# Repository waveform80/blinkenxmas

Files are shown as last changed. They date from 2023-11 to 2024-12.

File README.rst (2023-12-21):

=============
Blinken' Xmas
=============

Are you sitting comfortably? Then I'll begin …

A long time ago, in a land far, far away called "Manchester", there lived the
Jones family. At this festive time of year they would put up their ceremonial
totem, the "Asda 6ft Pre-Lit Green Christmas Tree". But 'twas the year of the
Great Plague, and even the electrickery faired poorly, and lo! The Asda 6ft
Pre-Lit Green Christmas Tree had become The Asda 6ft Not-Even-Slightly-Lit
Green Christmas Tree, not Pre-Lit, nor Lit, but possibly Post-Lit.

And all were most vexed.

In the great drawer of unstatic bags in the loft, there lived the `neopixies`_.
And they cried out, "use us, for we shall bring light and all manner of
blinkeness to your tree!" So the one called "Dave" gathered together 150 of the
neopixies, and waved his magic Pico at them [#wrong1]_, and the tree glowed
brightly with their warmth.

And it was Good.

But the neopixies were not content with glowing warm white all the time, and
whispered to Dave that they could make all the colours of the rainbow, if only
he would wave his magic Pico a bit more [#wrong2]_. And so Dave set to work,
and after much toil (and no small amount of "why is the tree dark? Can't you
just make it one colour, again? That was fine!"), the tree was lit once more,
but this time with all the colours of the rainbow! But the design was rough;
mere anarchy loosed upon the innocent eyeballs of the viewer [#sorry1]_. And
all who saw it did whisper, "it's very colourful, but in a unicorn vomit sort
of a way".

And lo! A `message from the Prophet Parker`_ did appear.

And it was good. If a bit thin on detail. I mean, where's the calibration trig?
But Dave was unperturbed and vowed that he would wrangle the neopixies with his
mathemagic and bring order to the Asda 6ft Unicorn-Vomit Christmas Tree. But
his `trigo-gnometry`_ had gathered dust for too many years, and his mathemagic
was not sufficient to the cause, so in the end he relented, and all had to be
content with a simple twinkling of the warm white lights that year.

The season passed, the Asda 6ft Post-Lit Green Christmas Tree was packed away,
and the neopixies returned to their drawer, awaiting their chance to shine like
crazy tetrahedral carbon crystals once more [#sorry2]_.

Time moved on, and in the waxing light of spring, the project appeared
forgotten. The neopixies wept as the Pico was waved at other things, like
to-martoes in the back garden, or o-ink paper, but never at them. But in the
waning light of autumn, as the nights closed in, they suddenly found themselves
freed once more. To their surprise, Dave bound them to a new creature known as
a "`picow`_". And the picow listened to a `mosquitto`_ that listened to a pie
that listened to a web that listened to strange beings called "yousers".

And Dave said "this is all getting a bit complex, and I still haven't figured
out this trigo-gnometry stuff".

So he sought `help from the wizards`_ who exchange stacks. And lo! The answer
arrived faster than a speeding pizza. And Dave was sore annoyed at himself that
the answer was so simple. But no matter, for now he could wield the
mathemagical power to control and conduct the mischievous neopixies in a
glorious symphony of light!

And so it came to pass that Dave procured
`even <https://shop.pimoroni.com/products/5m-flexible-rgb-led-wire-50-rgb-leds-aka-neopixel-ws2812-sk6812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>`_
`more <https://thepihut.com/products/adafruit-soft-flexible-wire-neopixel-strand-50-neopixels>`_
neopixies, swelling their orchestra until it was full 250 strong. And though
Dave was not disgruntled, he was far from gruntled [#sorry3]_ that this was but
half the count of `The Prophet Parker's most learned of trees`_. But no one
else was listening. For the yousers were too busy plucking the fibres of the
web to talk to the pie to talk to the mosquitto to talk to the picow to conduct
the neopixies into making the Asda 6ft Blinken Tree shine and shimmy and
glitter and blast Pride flags at the eyeballs of innocent bystanders.

In time, others versed in the ways of code saw the tree and said "have you
open-sourced it yet?", and Dave looked at his private suppository and said "but
there's no docs … or tests … or even type-hints?" And the others said "no one
cares, Dave, it's a Christmas tree, not a nuclear reactor".

And lo! Dave did flip the private switch and there was light! In all the
colours of unicorn vomit …

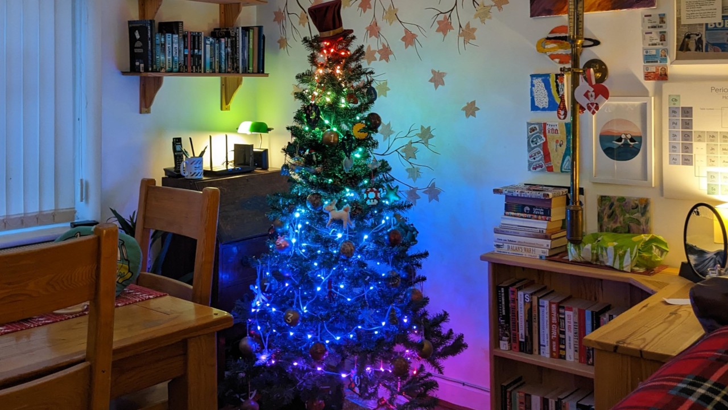
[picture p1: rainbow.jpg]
The 250 neopixies of the Asda 6ft Green Christmas Tree display a

          tasteful rainbow over the height of the tree.

----

.. _neopixies: https://en.wikipedia.org/wiki/Adafruit_Industries#NeoPixel
.. _message from the Prophet Parker: https://www.youtube.com/watch?v=TvlpIojusBE
.. _trigo-gnometry: https://en.wikipedia.org/wiki/List_of_trigonometric_identities
.. _help from the wizards: https://math.stackexchange.com/questions/4816183/radius-of-circle-given-horizontal-distances-of-two-points-and-angle-between-them/4816273
.. _The Prophet Parker's most learned of trees: https://www.youtube.com/watch?v=WuMRJf6B5Q4
.. _picow: https://www.raspberrypi.com/news/raspberry-pi-pico-w-what-did-you-think/
.. _mosquitto: https://mosquitto.org/

.. [#wrong1] That just sounds wrong -- Ed

.. [#wrong2] That's not getting any better, you know -- Ed

.. [#sorry1] With apologies to W.B. Yeats

.. [#sorry2] With apologies to Pink Floyd

.. [#sorry3] With no apologies at all to P.G. Wodehouse; damn you, that line's
   too good not to steal!

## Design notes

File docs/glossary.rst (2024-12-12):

===========
Glossary
===========

.. glossary::

    AWG
        `American Wire Gauge
        <https://en.wikipedia.org/wiki/American_wire_gauge>`_; a typically
        American measurement of conductive wire sizes.

    CPU
        `Central Processing Unit
        <https://en.wikipedia.org/wiki/Central_processing_unit>`_; the "brain"
        of a computer.

    CSI
        `Camera Serial Interface
        <https://en.wikipedia.org/wiki/Camera_Serial_Interface>`_; a standard
        interface for cameras in mobile or embedded systems. Notably the
        interface used by all Raspberry Pi models to connect camera modules (in
        various form factors).

    GPIO
        `General Purpose Input/Output
        <https://en.wikipedia.org/wiki/General-purpose_input/output>`_; in the
        context of :term:`SBCs <SBC>`, this typically refers to the prominent
        pin-header (often containing 2×20 pins) along one edge of the board.
        Some (but not all) of these pins may be controlled by software,
        operating as inputs or outputs.

    I²C
        The `Inter-Integrated Circuit
        <https://en.wikipedia.org/wiki/I%C2%B2C>`_ interface. A low-speed
        peripheral bus capable of connecting multiple peripherals sharing the
        same two wires for communication. Typically runs at a bandwidth of
        100Kbits/s. Commonly found exposed on the :term:`GPIO` headers of many
        :term:`SBCs <SBC>`.

    LED
        `Light Emitting Diode
        <https://en.wikipedia.org/wiki/Light-emitting_diode>`_. As the name
        suggests, a diode which emits light when conducating in the "forward"
        direction. The basic building block of a :term:`neopixel`.

        which
        typically contains three (or sometimes four) LEDs, one red, one green,
        one blue, and optionally one white (which typically provides better
        spectral output than the red, green, blue combination).

    neopixel
        A compound :term:`LED` typically consisting of red, green, blue, and
        optionally white LEDs which can be varied in intensity individually to
        produce any visible color. Comes in two major variants: WS2812 which
        uses a single :term:`PWM` data channel, and APA102 which is based upon
        the pre-existing :term:`I²C` protocol

    OS
        `Operating System <https://en.wikipedia.org/wiki/Operating_system>`_

    Pico
        Raspberry Pi's brand of micro-controller. Currently based on either the
        RP2040 or RP2350 chips, the major feature of the Pico (which Blinken'
        Xmas relies upon) is the :term:`PIO` state machines that enable it to
        control many neopixels without :term:`CPU` load.

    PIO
        `Programmable I/O
        <https://hackspace.raspberrypi.com/articles/what-is-programmable-i-o-on-raspberry-pi-pico>`_;
        the "unique" feature of the Raspberry Pi Pico which offloads
        :term:`GPIO` processing to one of several independent units that can
        read input or write output to GPIO pins without :term:`CPU`
        intervention (or load).

    PWM
        `Pulse Width Modulation
        <https://en.wikipedia.org/wiki/Pulse-width_modulation>`_; a technique
        of transmitting a signal as a rectangular wave with a regular or
        varying "duty cycle"

    SBC
        Single Board Computer. An abbreviation typically applied to small
        computers like the Raspberry Pi which encapsulate the entire computer
        (including display controller, and all peripheral interfaces) on a
        single board. Typically only applies to machines that run "full"
        multi-tasking operating systems (like Linux), but *not* to
        micro-controllers like the Pico which only run a single task
        (Micropython, for instance).

    SD card
        `Secure Digital <https://en.wikipedia.org/wiki/SD_card>`_ cards are a
        common persistent storage media used in :term:`SBCs <SBC>` consisting
        of small, thumbnail sized cards with read/write capacities typically
        measured in tens of gigabytes.

    SSH
        The `secure shell <https://en.wikipedia.org/wiki/Secure_Shell>`_
        protocol used to remotely access machines typically running a
        `Unix-like <https://en.wikipedia.org/wiki/Unix-like>`_ :term:`OS`

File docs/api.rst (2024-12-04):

=============
API Reference
=============

.. module:: blinkenxmas

The Blinken' Xmas code tries to be as reasonably self-contained as possible, to
avoid too many dependencies in order to make the packaging a bit easier and
low-maintenance longevity a bit more likely.

The following sections list the various modules in the Python code:

.. toctree::
    :maxdepth: 1

    api_animations
    api_calibrate
    api_cameras
    api_cli
    api_compat
    api_config
    api_flash
    api_http
    api_httpd
    api_mqtt
    api_routes
    api_store
    api_web

I'm afraid the Pico-side code is (currently) largely undocumented. However, it
is much simpler, and if you can understand the Pi-side of the code you'll
easily handle the Pico side.

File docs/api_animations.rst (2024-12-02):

======================
blinkenxmas.animations
======================

.. module:: blinkenxmas.animations

The :mod:`blinkenxmas.animations` module defines the animation functions
available for generating presets. Specifically, any function decorated with the
:func:`~blinkenxmas.httpd.animation` decorator is registered as an available
animation in the interface.

Animation functions can take an arbitrary set of
parameters. The decorator's parameters affect how the parameters of the
function will be rendered in the interface. For this reason, you are encouraged
to look at the full definition of each animation function *including its
decorator*. The function must return a :class:`list` of :class:`list` of
:class:`~colorzero.Color`. The outer list defines the "frames" of the
animation. Each inner list defines the color of each LED in index order.

For example, here is the full definition of :func:`gradient_by_index`:

.. code-block:: python3

    @animation('Gradient (by index)',
               led_count=ParamLEDCount(),
               color1=Param('From', 'color', default='#000000'),
               color2=Param('To', 'color', default='#ffffff'))
    def gradient_by_index(led_count, color1, color2):
        gradient = color1.gradient(color2, steps=led_count)
        return [[color for color in gradient]]

The decorator defines the title for the animation, and the label, type, and
defaults for each parameter. The result is a list of lists, but as there's only
one "frame" the outer list contains one item.

Animation functions
===================

.. autofunction:: one_color

.. autofunction:: gradient_by_index

.. autofunction:: gradient_by_pos

.. autofunction:: sweep_by_index

.. autofunction:: sweep_by_pos

.. autofunction:: flash

.. autofunction:: twinkle

.. autofunction:: rainbow_by_index

.. autofunction:: rainbow_by_pos

.. autofunction:: scrolling_rainbow_by_index

.. autofunction:: spinning_rainbow

.. autofunction:: pride_flags

Utility functions
=================

.. autofunction:: scale

.. autofunction:: range_of

.. autofunction:: pairwise

.. autofunction:: preview

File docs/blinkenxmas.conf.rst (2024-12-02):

================
blinkenxmas.conf
================

All applications in the Blinken' Xmas suite read their configuration from the
following locations:

* :file:`/usr/local/etc/blinkenxmas.conf`

* :file:`/etc/blinkenxmas.conf`

* :file:`{$XDG_CONFIG_HOME}/blinkenxmas.conf` where $XDG_CONFIG_HOME is
  typically :file:`~/.config`

If multiple of these exist, they are read in the order above with settings in
later files overriding settings from earlier ones. The configuration file
format is based on the common `INI file`_ format.

The following sections document the available settings.

[mqtt]
======

Configures the MQTT broker that :program:`bxweb` and :program:`bxcli` post to,
and to which the Pico will listen.

host
    The hostname of the MQTT broker. Even if the broker is present on the local
    machine, this must be set to a "proper" hostname, i.e. something other than
    "localhost". Default: "broker"

    This configuration is also used to generate the Pico's configuration, which
    will need the actual network address.

port
    The port on which the MQTT broker will be listening. May be specified as an
    integer or a registered service name. Default: 1833.

topic
    The topic to which the Pico should subscribe, and to which the web
    application will publish new animations for the tree to play.

[web]
=====

Settings specific to the :program:`bxweb` application.

bind
    The address to which :program:`bxweb` should bind and listen for
    connections. If you are running the application "bare" this should be set
    to "0.0.0.0" or "::" to bind to all interfaces. If you are using a reverse
    proxy, this should be set to "127.0.0.1" (the default) or "::1".

port
    The port on which :program:`bxweb` should listen for connections. If you
    are running the application "bare" this should be 80 (or 443 if you can be
    bothered to set up HTTPS for an xmas tree!). If you are running this behind
    a reverse proxy, this should be set to an unprivileged port like 8000 (the
    default).

database
    The path to the SQLite database used by :program:`bxweb` and
    :program:`bxcli` to store and retrieve preset animations, and tree LED
    coordinates.

[wifi]
======

Configures the wifi access point that the Pico connects to. Used by
:program:`bxflash` to generate the Pico's configuration.

ssid
    The SSID of the wifi access point that the Pico should attempt to connect
    to on startup.

password
    The password of the wifi access point that the Pico should use. Currently
    there is no support for anything other than basic PSK authentication.

[pico]
======

Configuration settings specific to the Pico. These are used by
:program:`bxflash` to generate the code uploaded to the Pico.

status
    The GPIO number (or name) of the status LED on the Pico. This is flashed
    in various patterns to indicate the current state. Defaults to "LED" which
    is the built-in LED on the Pico W.

error
    The action to take on a fatal error. May be set to "reset" (the default) to
    reboot the Pico, or "flash" to terminate and flash the status in a regular
    pattern. The "flash" setting is primarily intended for debugging as it
    permits connection to the serial console to query state.

[camera]
========

This section defines the camera used by :program:`bxweb` to calibrate the
positions of the LEDs on the tree.

type
    The type of camera available to the system running :program:`bxweb`. Can be
    set to one of:

    none
        No camera is available for tree calibration. The default.

    picamera
        Uses the legacy :mod:`picamera` library to control a Raspberry Pi
        camera module attached to the local system (which is presumably a
        Raspberry Pi)

    gstreamer
        Uses the GStreamer framework to query a V4L2 video source, typically a
        USB web-camera).

    files
        Uses a pre-captured set of JPEG images to emulate a camera. Primarily
        intended for development and testing purposes.

device
    When *type* is "gstreamer", the path of the V4L2 video source. Defaults to
    :file:`/dev/video0`

path
    When *type* is "files", the path of the pre-captured files. See
    :class:`blinkenxmas.cameras.FilesSource` for further details of the file
    naming convention expected.

capture
    The resolution at which to capture images, specified as a "WIDTHxHEIGHT"
    value, e.g. "1920x1080". For accuracy reasons, this should be set to the
    native capture resolution of the camera device, e.g. "2592x1944" for a v1
    Pi camera module.

preview
    The resolution at which to capture video for the web-based preview,
    specified as a "WIDTHxHEIGHT" value, e.g. "640x480". For performance
    reasons, this should generally be set to quite a low resolution.

[leds:\*]
=========

These sections define the various LED strips that are attached to the tree. At
least 1, and up to 8 of these sections may be defined. The "*" in the section
title is arbitrary and simply used to distinguish the sections.

driver
    Set to either "WS2812" or "APA102" depending on the sort of neopixels
    present in the strip.

pin
    When *driver* is "WS2812", specifies the GPIO pin connected to the data pin
    of the neopixels in the strip.

dat, clk
    When *driver* is "APA102", specifies the GPIO pins connected to the DAT
    (data) and CLK (clock) pins of the neopixels in the strip, respectively.

count
    The number of neopixels in the strip. Typically some multiple of 50.

order
    Specifies the color ordering expected by the neopixels in the strip.
    Usually "RGB" or "GRB", but any combination of R, G, and B is accepted,
    e.g. "BGR". If the neopixels include a separate white channel, append "W"
    to the value, e.g. "RGBW" or "GRBW".

fps
    The maximum refresh rate to apply to the neopixels in the strip. Defaults
    to 60.

    .. note::

        Dropping this to 30 can considerably speed up tranmission of animations
        as it halves the amount of data involved, but with obvious implications
        for the smoothness of animation.

reversed
    If "no" (the default), the neopixels are addressed from the "start" of the
    strip; if "yes", from the end.

    This is primarily useful in non-calibrated installations where you are
    relying on the position along the strip for certain effects, have multiple
    strips, and want one strip to "continue" an animation from the top of the
    tree (the end of another strip) back to the bottom.

Example
=======

.. literalinclude:: ../blinkenxmas/default.conf
    :language: ini
    :caption: /etc/blinkenxmas.conf

.. _INI file: https://en.wikipedia.org/wiki/INI_file

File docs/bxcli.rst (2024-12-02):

.. program:: bxcli

=====
bxcli
=====

The command line interface for the Blinken' Xmas project. Provides a simple
command line which can load or delete an existing preset, set all LEDs to a
specific color, or set an individual LED to a specified color.

Synopsis
========

::

    bxcli [-h] [--version] [--broker-address ADDR] [--broker-port NUM]
          [--topic TOPIC] {command} ...

Options
=======

.. option:: -h, --help

    Show the help message and exit

.. option:: --version

    Show program's version number and exit

.. option:: --broker-address ADDR

    The address on which to find the MQTT broker. Default: broker

.. option:: --broker-port NUM

    The port on which to find the MQTT broker. Default: 1883

.. option:: --topic TOPIC

    The topic on which the Pico W is listening for messages. Default: blinkenxmas

.. option:: command

    See `Commands`_ below

Commands
========

help [command]
    Display help on the specified *command*, or a summary of all commands

off
    Switch all LEDs off

on {color}
    Switch all LEDs on with the specified *color*, given as a common CSS3 color
    name, or an HTML color code in the form #RRGGBB, e.g. #FF0000 for red.

set {index} {color}
    Set LED *index* to the specified *color*. The *index* is simply an integer
    number counting from 0..n-1 where *n* is the total number of LEDs present
    in the tree. The *color* is given as a common CSS3 color name, or an HTML
    color code in the form #RRGGBB.

list
    Display the names of all presets currently stored in the database on the
    terminal.

show {preset}
    Display the specified *preset* on the tree. Note that preset names
    containing special characters or spaces will likely need quoting on the
    command line.

Debugging
=========

The **on** command is particular useful for testing your setup. To ensure your
power setup is adequate (and adequately isolated), try:

.. code-block:: console

    $ bxcli on "#ffffff"

This should switch all LEDs on at full white (shield your eyes!). If your Pico
crashes, you are likely using a single supply (or single rail on a single
supply) for both your LEDs and the Pico. This is likely to fail when there are
sudden fluctuations in the brightness of the LEDs, leading to brief voltage
drops on the line.

Assuming everything does light correctly, and the Pico doesn't crash, leave the
tree fully lit for a minute, and check the heat of the cables running from your
power supply to the neopixels. If they are too hot to touch, you are strongly
advised to replace those cables with something thicker.

See Also
========

:doc:`bxweb`, :doc:`bxflash`, :doc:`blinkenxmas.conf`

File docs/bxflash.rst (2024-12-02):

.. program:: bxflash

=======
bxflash
=======

Flash the BlinkenXmas code to a Pico for use on an xmas tree.

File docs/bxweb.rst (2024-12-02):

.. program:: bxweb

=====
bxweb
=====

The HTTP server for the Blinken' Xmas project. Provides a simple web-interface
for building tree animations and serving them over MQTT to the Pico connected
to the neopixels on the tree.

Synopsis
========

::

    bxweb [-h] [--version] [--broker-address ADDR] [--broker-port NUM]
          [--topic TOPIC] [--httpd-bind ADDR] [--httpd-port PORT]
          [--no-production] [--production] [--db FILE]

Options
=======

.. option:: -h, --help

    Show the help message and exit

.. option:: --version

    Show program's version number and exit

.. option:: --broker-address ADDR

    The address on which to find the MQTT broker. Default: broker

.. option:: --broker-port NUM

    The port on which to find the MQTT broker. Default: 1883

.. option:: --topic TOPIC

    The topic on which the Pico W is listening for messages. Default:
    blinkenxmas

.. option:: --httpd-bind ADDR

    The address on which to listen for HTTP requests. Default: 0.0.0.0

.. option:: --httpd-port PORT

    The port to listen for HTTP requests. Default: 8000

.. option:: --no-production, --production

    If specified, run in production mode where an internal server error will
    not terminate the server and will not output a stack trace (default: no)

.. option:: --db FILE

    The SQLite database to store presets in. Default:
    :file:`/var/local/cache/blinkenxmas/presets.db`

Configuration
=============

This application is a basic no-frills HTTP server producing the web front-end.
While it is multi-threaded, it isn't intended to scale to large numbers of
users, because there's no need with a single tree! Moreover, there's no
authentication, and no assumptions should be made as to the application's
security. To run this on the standard port 80 (or 443), you are recommended to
place the application on an unprivileged port (e.g. the default of 8000),
running as an unprivileged user, and place a reverse proxy (like nginx) in
front of it.

A sample :manpage:`systemd.unit(5)` for execution of the application is:

.. literalinclude:: ../blinkenxmas-web.service
    :language: systemd
    :caption: /etc/systemd/system/blinkenxmas-web.service

.. note::

    At the time of writing, the application does not support systemd's
    notify mechanism, or socket activation.

A sample reverse proxy for nginx is:

.. literalinclude:: ../blinkenxmas.nginx
    :language: nginx
    :caption: /etc/nginx/sites-available/blinkenxmas

Environment
===========

.. envvar:: DEBUG

    If set to "1", the application will produce a full stack-trace on any
    fatal exception. If set to "2", the application will jump to PDB for
    exception post-mortem on any fatal exception.

See Also
========

:doc:`bxcli`, :doc:`bxflash`, :doc:`blinkenxmas.conf`

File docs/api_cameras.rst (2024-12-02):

===================
blinkenxmas.cameras
===================

.. module:: blinkenxmas.cameras

The :mod:`blinkenxmas.cameras` module defines abstractions for the various
camera backends that Blinken' Xmas supports. The classes are as follows:

Camera classes
==============

.. autoclass:: AbstractSource

.. autoclass:: FilesSource

.. autoclass:: PiCameraSource

.. autoclass:: GStreamerSource

Support classes
===============

.. autoclass:: PiCameraOutput

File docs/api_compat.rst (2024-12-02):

==================
blinkenxmas.compat
==================

.. module:: blinkenxmas.compat

This module exists solely to provide back-ported classes from later versions of
Python. Currently it only contains a back-port of
:class:`tempfile.SpooledTemporaryFile` for Python versions below 3.11.

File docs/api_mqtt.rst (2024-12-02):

================
blinkenxmas.mqtt
================

.. module:: blinkenxmas.mqtt

The :mod:`blinkenxmas.mqtt` module defines the :class:`MessageThread` class,
the thread used by :program:`bxweb` and :program:`bxcli` to communicate with
the MQTT broker.

Classes
=======

.. autoclass:: MessageThread

Support functions
=================

.. autofunction:: render

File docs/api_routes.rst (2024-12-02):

==================
blinkenxmas.routes
==================

.. module:: blinkenxmas.routes

The :mod:`blinkenxmas.routes` module defines all the dynamically generated
routes registered with the HTTP server for the :program:`bxweb` application.

Route functions
===============

.. autofunction:: home

.. autofunction:: get_messages

.. autofunction:: get_presets

.. autofunction:: get_preset

.. autofunction:: del_preset

.. autofunction:: set_preset

.. autofunction:: preview

.. autofunction:: preview_preset

.. autofunction:: generate_animation

.. autofunction:: calibration_positions

.. autofunction:: calibration_preview

.. autofunction:: calibration_base

.. autofunction:: calibration_mask

.. autofunction:: calibration_state

.. autofunction:: calibration_run

.. autofunction:: calibration_cancel

.. autofunction:: calibration_result

.. autofunction:: calibration_commit

Support functions
=================

.. autofunction:: scanner_for

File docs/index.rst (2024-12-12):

Welcome to Blinken' Xmas! A project to display a tasteful assortment of
positively festive animations across strings of neopixels adorning your
Christmas tree. Or a project to blast screaming rainbows into the eyeballs of
your nearest and dearest. I take no responsibility for your choices.

The 250 neopixies of the Asda 6ft Green Christmas Tree display a
          tasteful rainbow over the height of the tree.

The :doc:`tutorial` is probably the best place to start as it'll walk you
through all the hardware configuration, and software installation. If you want
to hack on the project, it's pretty easy to add animations; see the
:doc:`development` chapter on getting started.

.. warning::

    The documentation is still very incomplete...

Contents
========

.. toctree::
    :maxdepth: 1

    tutorial
    applications
    api
    development
    changelog
    license
    glossary

Indices and tables
==================

* :ref:`modindex`
* :ref:`genindex`

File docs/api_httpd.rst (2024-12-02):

=================
blinkenxmas.httpd
=================

.. module:: blinkenxmas.httpd

The :mod:`blinkenxmas.httpd` module extends the standard library's
:mod:`http.server` with handling functions for form-data, JSON content, and a
mechanism to route requests to static content, :mod:`chameleon` generated
content, or dynamic functions.

It also defines the :class:`HTTPThread` class, the main thread used by the
:program:`bxweb` application to service HTTP clients, the :func:`route`
decorator used to associate handler functions with their HTTP virtual path (see
:mod:`blinkenxmas.routes`), and the :func:`animation` decorator used to declare
LED animation generators for the main interface.

HTTP handlers
=============

.. autofunction:: route

.. autoclass:: HTTPServer

.. autoclass:: HTTPRequestHandler

.. autoclass:: HTTPThread

Animation handlers
==================

.. autofunction:: animation

.. autoclass:: Function

.. autoclass:: Param

.. autoclass:: ParamLEDCount

.. autoclass:: ParamLEDPositions

.. autoclass:: ParamFPS

Support functions
=================

.. autofunction:: get_best_family

.. autofunction:: for_commands

.. autoclass:: Messages

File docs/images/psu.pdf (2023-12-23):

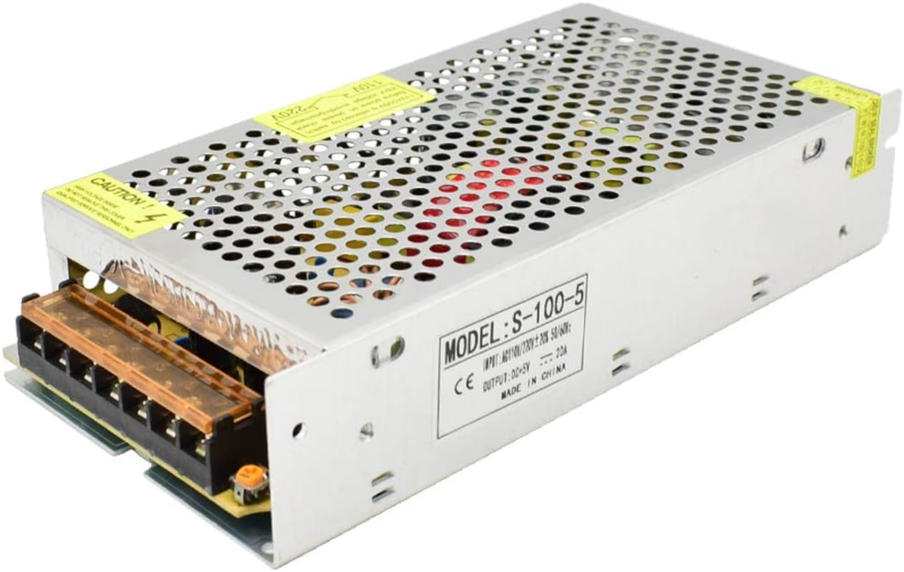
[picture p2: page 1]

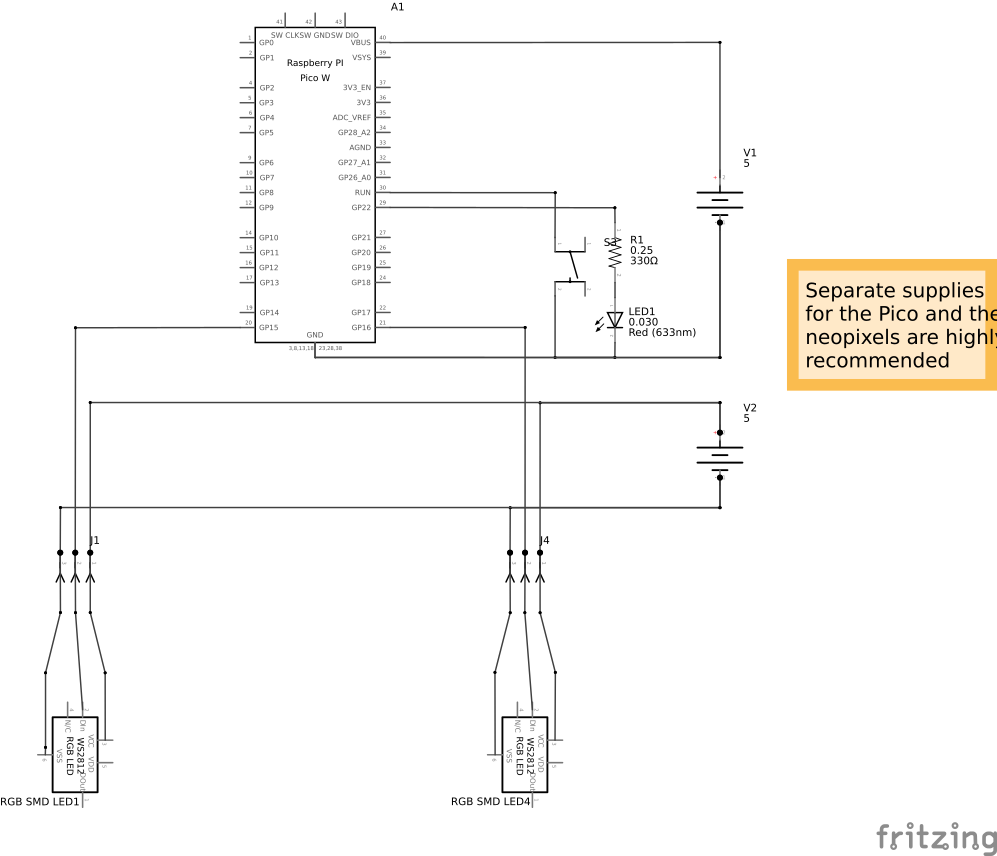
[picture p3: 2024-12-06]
docs/images/schematic.png

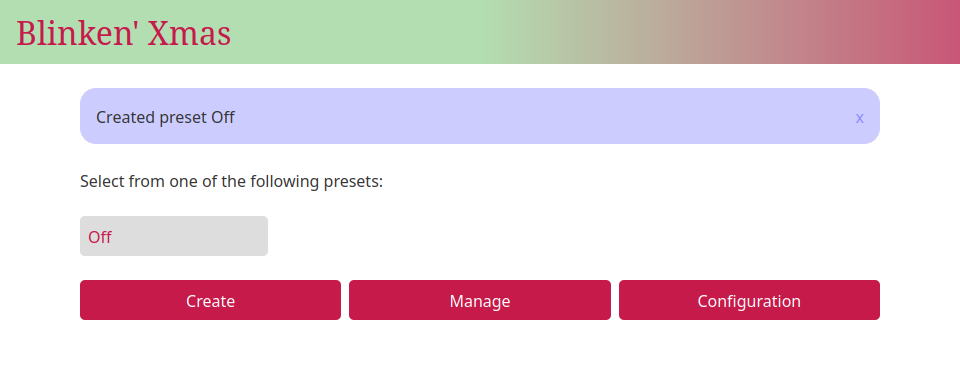
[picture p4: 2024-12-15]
docs/images/ui3.png

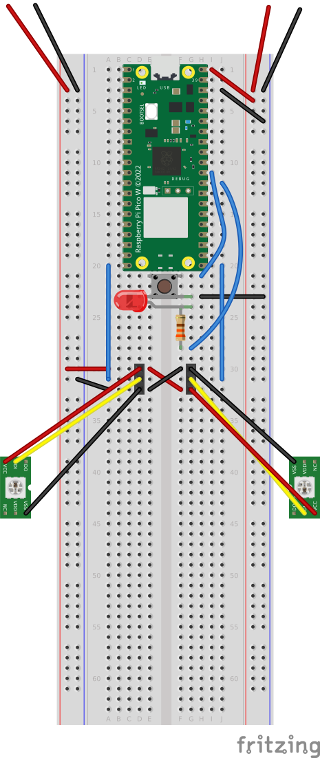
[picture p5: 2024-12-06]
docs/images/breadboard.png

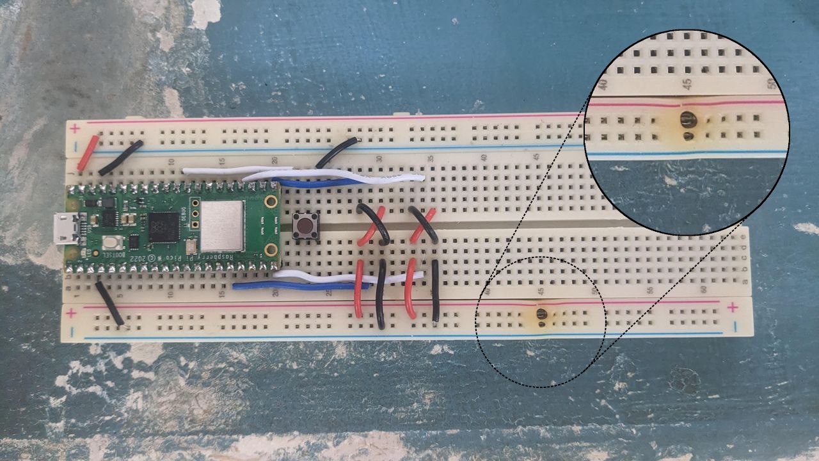
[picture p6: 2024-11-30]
docs/images/el_scorchio.jpg

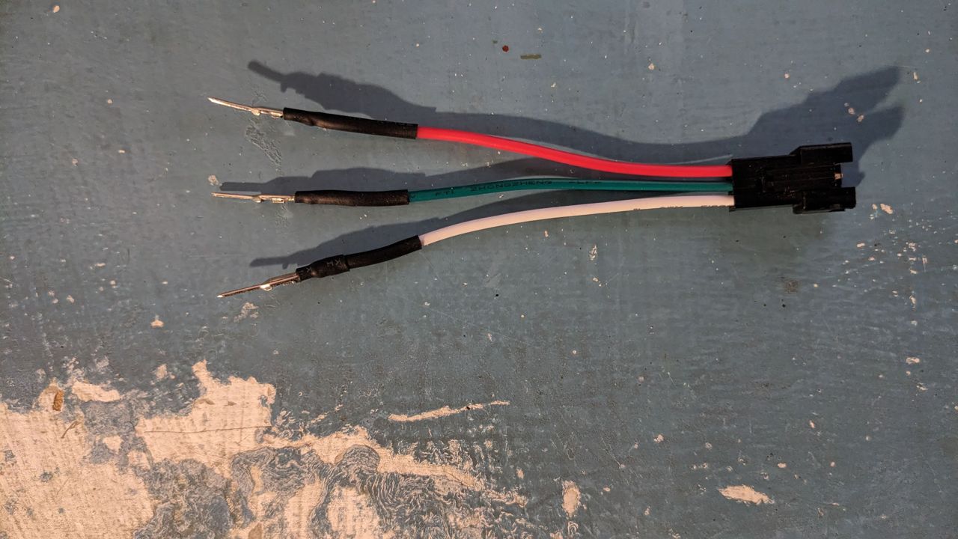
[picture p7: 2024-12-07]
docs/images/crimped_connector.jpg

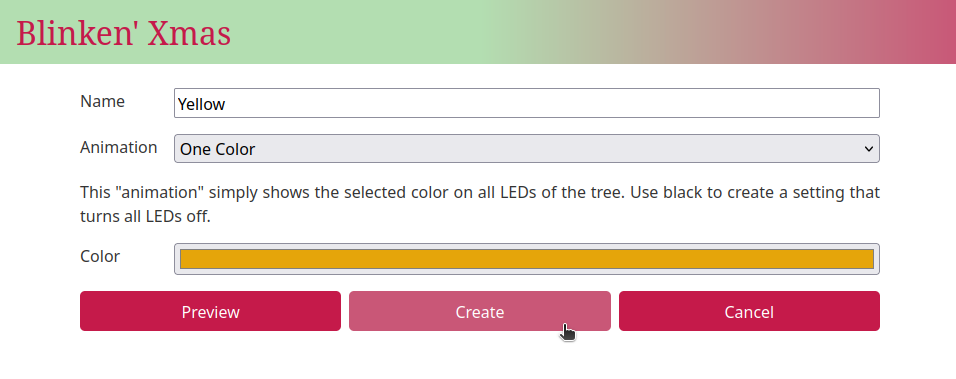
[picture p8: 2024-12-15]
docs/images/ui4.png

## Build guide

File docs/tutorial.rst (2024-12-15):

========
Tutorial
========

This tutorial will guide you through setting up Blinken' Xmas on your Christmas
tree, with multiple strands of neopixels attached to the Pico, and a Raspberry
Pi with a camera module for the server to perform calibration on the positions.

.. note::

    Please be aware this is *not* a quick set up you are likely to finish in an
    afternoon. However, once the hardware side is put together, setting things
    in future years can indeed be accomplished quite quickly (in about an hour,
    from experience).

.. toctree::
    :maxdepth: 1

    tutorial1
    tutorial2
    tutorial3
    tutorial4
    tutorial5
    tutorial6

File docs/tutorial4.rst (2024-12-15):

==========
Pico Setup
==========

As on the Pi, the first thing to do with the :term:`Pico` is get some software
onto it.

.. warning::

    You are about to erase everything on your Pico W. If you've got any code
    saved on there that you want to preserve, take a copy of it first.

The first thing to load is a special MicroPython build which includes
Pimoroni's fabulous "plasma" library. One of the following should suffice,
depending on your model of Pico:

2040-based Pico W
    `pimoroni-pico releases`_

2350-based Pico 2W
    `pimoroni-pico-rp2350 releases`_

For reference, I've used pimoroni-pico 1.21.0 on a Pico W, and
pimoroni-pico-rp2350 0.0.10 on a `Pico Plus 2W`_, but you should probably just
grab the latest build for your specific board. The file should have a name
something like :file:`{board}-{version}-pimoroni-micropython.uf2`.

Find a cable suitable for connecting your :term:`Pico` to your computer, but
don't connect it just yet! Plug one end of the cable into your computer, then
hold down the "BOOTSEL" button on the Pico while inserting the other end of the
cable into the Pico. Continue holding the button for about a second after
you've inserted the cable. This procedure puts the Pico into a mode where you
can re-flash it.

Shortly after, you should see the drive "RPI-RP2" appear. Copy the
pimoroni-pico firmware you downloaded (the
:file:`{board}-{version}-pimoroni-micropython.uf2` file) to this drive. It
should take a few seconds to copy, then a brief time later you should see the
drive disappear again. This indicates the Pico has accepted the firmware and
has rebooted into MicroPython.

Unplug the Pico W from your computer, and plug it into your Raspberry Pi. Now
run the :program:`bxflash` application to copy the Blinken' Xmas script to the
Pico:

.. code-block:: console

    $ bxflash
    Copying mqtt_as.py
    Copying config.py
    Copying blinkenxmas.py
    Copying main.py
    Copying leds.py
    Copying animation.py

At this point all the software installation on both Pi and Pico is done. Time
to move onto the hardware.

Wiring
======

Now it's time to put your :term:`Pico` together with the breadboard. You're
aiming for the following layout where the :term:`neopixel` on the left
represents the start of the 50 neopixel strip (connected to :term:`GPIO` 15),
and the strip on the right (connected to GPIO 16) represents the start of the
100 neopixel strip.

A breadboard diagram showing the layout of the Pico, neopixels, reset
          button, status LED, and power rails

The power cables off the top of the board are deliberately separate. The wires
on the left rails supply power to the neopixels. The wires on the right rails
supply power to the Pico (via VBUS and ground). These should either be
connected to separate rails of your supply, or entirely separate supplies. In
the latter case, run a cable between the negative rails on each side of the
breadboard to ensure everything has a common ground.

A momentary button connects the Pico's RUN pin to ground so that we can easily
hard-reset the Pico if the software locks up for any reason. Finally, GPIO 22
connects to a 330Ω resistor, then an :term:`LED`, then ground to provide a
crude means for the Pico to report status to us (by blinking the LED in various
patterns).

.. note::

    Why not use the LED built into the Pico? Or the reset button present on the
    Pico Plus 2W? Ultimately the Pico and its (bulky) power supply are going to
    be housed in some sort of box to keep small fingers from poking around near
    mains electricity. Unless that box is transparent, it's going to be
    difficult to see the Pico's own LED. Also, while "turning it off and on
    again" is certainly an option for resetting the Pico, a simple momentary
    button is even easier.

    In my current setup, the reset button and status LED are combined into a
    single nice, big, `illuminated button`_ attached to the housing.

This is also the point where you will need to make sure your neopixel strips
have some suitable connections to the breadboard. At its most basic, soldering
some solid-core wire onto the terminals can work. However, where possible I'd
recommend either purchasing sets with pins pre-soldered (although these can be
quite difficult to come by), or buying a set of crimpers and connectors to make
your own connectors (preferably with some heat-shrink for insulation):

A crimped three-pin connector for a neopixel strip

Ideally, you want your :term:`neopixel` connector to stand off from the
breadboard so that it can sit outside your box, and to be irreversible so that
you can't mix up the +5V and ground lines. Typically, wiring for WS2812 (3-pin)
neopixels places the data pin in the middle with the +5V and ground lines
either side. In the picture above, the +5V line is red, the data line is green,
and the ground line is white. The connector on the right can only be mated one
way around, so provided the connections on the breadboard are correct, you will
be unable to connect your neopixel strip the wrong way around.

With the breadboard populated, wire the +5V and ground rails to the relevant
connectors on your power supply.

Housing and installation
========================

With the breadboard fully populated, it's time to install everything in a box.
Prepare a mains cable for the power supply, and install it through an
appropriately sized cable gland in the box for strain relief. Attach the power
supply to the interior of the box by whatever means is convenient. Typical
plastic project boxes may have screw-mount points pre-moulded inside them, but
it's also fine to drill through most such boxes and attach screws to mount the
power supply. Just be sure that any ventilation holes on the power supply
remain uncovered.

Mount the breadboard within the box. Most breadboards have a self-adhesive
backing that is convenient for this purpose. Again, ensure you do not cover
ventilation holes on the power supply, and keep any bare conductors on the
breadboard away from the power supply. Ideally, your box should be large enough
to accommodate power supply and breadboard side by side, but if yours is not
ensure there is adequate separation to avoid any shorts, and to allow free air
flow over the power supply.

Make some holes for the neopixel connectors. Cable glands may be used here, but
aren't as important as for the mains cable which definitely requires strain
relief.

I would recommend the following order for setting up the tree itself:

#. Locate the tree where you like, but ensure a power socket is reasonably
   nearby so that you're not trailing mains cables across the floor

#. Decorate the tree with all the baubles and trinkets you want, *except* the
   neopixel strands

#. Add the neopixels strands

   #. For each strand, start with the unconnected end at the top of the tree
      and wind it around in a spiral until you reach the bottom

   #. Once all strands are on, re-arrange the bottom until the ends that you
      want to connect to the Pico are all gathered together

   #. Use a cable tie to ensure the bottom of the strands stay together

#. Place your housing containing the power supply and Pico under the tree, and
   connect the strands to it

.. _Pico Plus 2W: https://shop.pimoroni.com/products/pimoroni-pico-plus-2-w
.. _pimoroni-pico releases: https://github.com/pimoroni/pimoroni-pico/releases
.. _pimoroni-pico-rp2350 releases: https://github.com/pimoroni/pimoroni-pico-rp2350/releases
.. _illuminated button: https://thepihut.com/products/rugged-metal-pushbutton-with-blue-led-ring

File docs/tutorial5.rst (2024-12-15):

==========
First Boot
==========

At this point, your hardware and software installation is complete. It's time
to test the basic (uncalibrated) operation to make sure everything is working.

#. Your Pi should already be booted, and you should be able to view the
   Blinken' Xmas web page at "blinkenxmas.local" on your network

#. Plug the Pico's housing into the wall socket

#. Watch the status LED and cross your fingers!

If everything goes correctly, you should see the Pico's status :term:`LED`
start to flash periodically, before eventually staying on. The flashes of the
status LED indicate the following:

2 flashes
    Indicates the Pico has booted Micropython and is trying to connect to the
    wifi AP

3 flashes
    The Pico has connected to the configured wifi AP and is trying to connect
    to the MQTT broker

solid
    The Pico has connected to the broker and is awaiting animations to display

5 flashes
    The Pico's script has crashed and it is not configured to reset
    automatically (by default, it will simply restart in this event)

Troubleshooting
===============

If the LED eventually turns solid, and you can see the web interface, skip this
section. Otherwise, check the following:

no flashes
    * Check the mains wiring to the power supply

    * Check the 5V wiring from the supply to your Pico

    * Check you've connected the status LED to the correct GPIO pin

    * Check that the LED is connected the right way around

2 flashes
    * Check the Pico's wifi configuration is correct

3 flashes
    * Check the Pico's MQTT configuration is correct (especially that the
      ``host`` setting is not ``localhost``, which will work on the Pi, but no
      the Pico)

5 flashes
    * Check the Pico was flashed correctly

    * Re-flash the base Pimoroni firmware (possibly downgrading to one of the
      versions mentioned specifically, earlier)

no web interface
    Plug the Pi into a monitor and keyboard. Make sure it has booted, and that
    the ``nginx`` and ``blinkenxmas-server`` services are running:

    .. code-block:: console

        ubuntu@tree:~$ systemctl status nginx.service
        ● nginx.service - A high performance web server and a reverse proxy server
             Loaded: loaded (/lib/systemd/system/nginx.service; enabled; vendor preset: enabled)
             Active: active (running) since Thu 2024-12-12 20:42:41 UTC; 2 days ago
               Docs: man:nginx(8)
           Main PID: 12846 (nginx)
              Tasks: 5 (limit: 1848)
             Memory: 4.0M
                CPU: 889ms
             CGroup: /system.slice/nginx.service
                     ├─12846 "nginx: master process /usr/sbin/nginx -g daemon on; master_process on;"
                     ├─12847 "nginx: worker process" "" "" "" "" "" "" "" "" "" "" "" "" "" "" "" "" "" "" "" "" "" "" "" "" "" "" ""
                     ├─12848 "nginx: worker process" "" "" "" "" "" "" "" "" "" "" "" "" "" "" "" "" "" "" "" "" "" "" "" "" "" "" ""
                     ├─12849 "nginx: worker process" "" "" "" "" "" "" "" "" "" "" "" "" "" "" "" "" "" "" "" "" "" "" "" "" "" "" ""
                     └─12850 "nginx: worker process" "" "" "" "" "" "" "" "" "" "" "" "" "" "" "" "" "" "" "" "" "" "" "" "" "" "" ""

        Dec 12 20:42:41 tree systemd[1]: Starting A high performance web server and a reverse proxy server...
        Dec 12 20:42:41 tree systemd[1]: Started A high performance web server and a reverse proxy server.
        ubuntu@tree:~$ systemctl status blinkenxmas-server.service 
        ● blinkenxmas-server.service - Blinkenxmas web service
             Loaded: loaded (/lib/systemd/system/blinkenxmas-server.service; enabled; vendor preset: enabled)
             Active: active (running) since Sat 2024-12-14 06:35:18 UTC; 1 day 11h ago
           Main PID: 28982 (bxweb)
              Tasks: 10 (limit: 1848)
             Memory: 43.4M
                CPU: 2min 50.210s
             CGroup: /system.slice/blinkenxmas-server.service
                     └─28982 /usr/bin/python3 /usr/bin/bxweb --production

        Dec 14 15:55:26 tree bxweb[28982]: 127.0.0.1 - - [14/Dec/2024 15:55:26] "GET / HTTP/1.0" 301 -
        Dec 14 15:55:26 tree bxweb[28982]: 127.0.0.1 - - [14/Dec/2024 15:55:26] "GET /index.html HTTP/1.0" 200 -

Switch on time!
===============

Once everything is running successfully, visit the web interface. You should
see a notice that no presets have been defined yet.

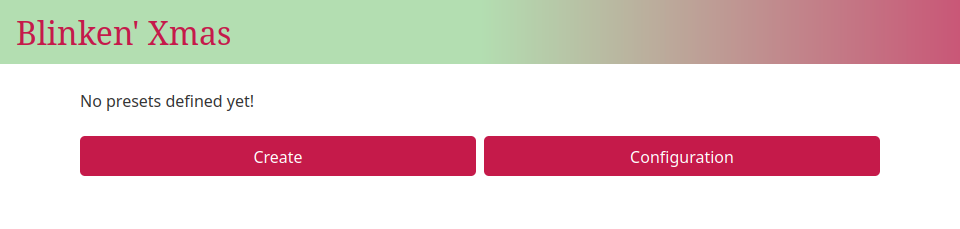
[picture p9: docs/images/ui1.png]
The Blinken' Xmas homepage showing no presets, and two buttons at

          the bottom labeled "Create" and "Configuration"

Let's correct that by
defining some very basic presets which will work even without calibration.

#. Select "Create"

#. Set the name to "Off"

#. Pick "One Color" from the list of animations

#. Pick black in the color picker that appears

#. Select "Create"

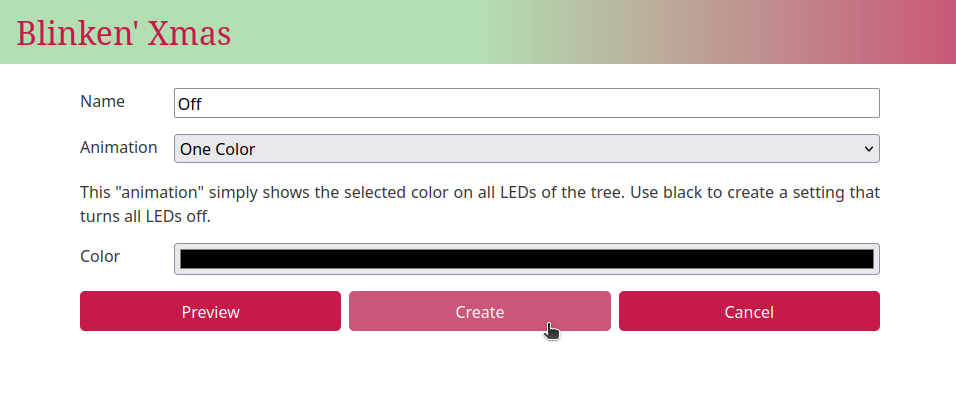
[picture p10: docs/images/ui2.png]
The Blinken' Xmas preset creation page showing the most basic layout

          of name, animation, and color options.

You should find yourself back on the home screen with a message indicating the
"Off" preset was created. Now that we have the most boring possible preset,
let's check the LEDs are working. Create a simple yellow preset:

#. Select "Create"

#. Set the name to "Yellow"

#. Pick "One Color" from the list of animations

#. Pick a relatively dark yellow from the color picker

#. Select "Preview" and watch the LEDs on the tree light up yellow

#. Select "Create"

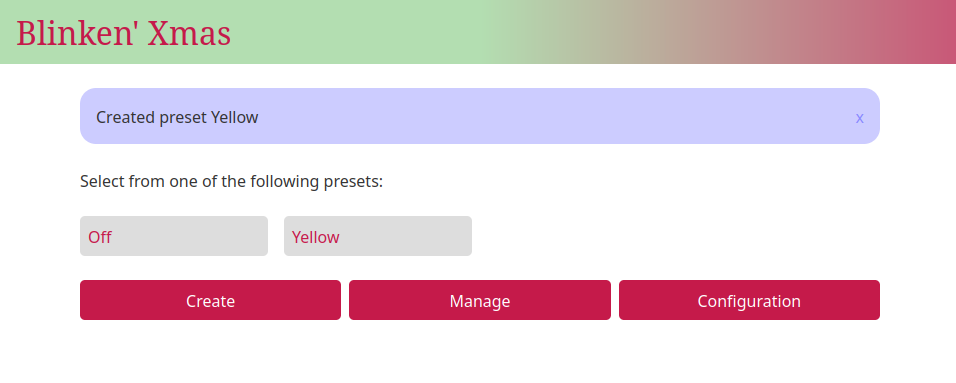
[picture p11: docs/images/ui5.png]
The Blinken' Xmas main page showing the "Off" and "Yellow" presets.


Back at the main page you can toggle between "Yellow" and "Off" by selecting
the presets. Time for something more colorful:

#. Select "Create"

#. Set the name to "Rainbows"

#. Pick "Scrolling Rainbow (by index)" from the list of animations

#. Set "Duration" to the middle of the range

#. Select "Create"

Back at the main page, select "Rainbows" from the list of presets. Your treat
should (after a short delay) light up with all the colors of the rainbow which
should gradually shift through the spectrum on all the LEDs. While very
colorful, it should also be obvious that the rainbow isn't particularly
coordinated.

This is because we are display a single rainbow along all our neopixels.
However, our LEDs are split into two uneven groups of 50 LEDs and 100 LEDs. If
we want a rainbow that coordinates its display across the height of the tree,
we're going to need to calibrate the positions of our LEDs...

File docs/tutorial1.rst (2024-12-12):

Requirements
============

You will need to be comfortable doing the following:

* Soldering, unless you buy a :term:`Pico` WH with the headers pre-soldered

* Crimping, unless all your :term:`LED` strips have connectors suitable for a
  breadboard pre-crimped onto them

* Wiring a mains power lead to a power supply; this just means some wire in
  some screw terminals, but you need to be confident you know which wires are
  live, neutral, and ground. If you're not confident (and/or competent!) in
  this, *please* get help from someone who is.

* Using :term:`SSH`, *preferably* using pub-key authentication

* Running commands at a Linux command line

* Editing a text configuration file from the Linux command line using ``nano``,
  ``vim``, or your favourite console text editor (you can try copying stuff
  back and forth, but given there'll be some user switching involved you are
  *much* better off just being able to edit things at the command line)

Shopping List
=============

You'll need the following bits of hardware to follow this tutorial. Don't worry
if you have fewer neopixels, or a slightly different model of Pi. Hints on
adjusting the instructions to other configurations will be included along the
way:

* A Christmas tree

* A WiFi capable network

* A Raspberry Pi; I'm using a `3B+`_ but any model [#pi5]_ with a :term:`CSI`
  camera port should work

* A camera for your Pi; I'm using an old v1 camera module, but you can use
  later models [#v3]_ too or even a web-cam [#webcam]_

* An :term:`SD card` for your Pi; I'm using a spare 32GB SanDisk Ultra card

* A power supply for your Pi; micro-USB for models older than the 4B, USB-C for
  the 4B or later

* A `Pico W`_, or some variant thereof (including a `Pico 2W`_, `Pico Plus
  2W`_, etc.); note you need a WiFi capable variant (not the bare Pico), and
  that this project relies on the :term:`Pico`'s specific capabilities
  [#othermcu]_

* A `breadboard`_ large enough to mount your Pico and all associated wiring

* A momentary push-button suitable for mounting on a breadboard

* A red :term:`LED`

* A 330Ω resistor

* `Jumper leads`_ or solid-core wire

* A 5V power supply capable of driving the :term:`Pico` (easy) and all your
  neopixels (harder); a typical micro-USB supply is *not* going to cut the
  mustard here but I'll go into more details below

* As many strands of WS2812 or APA102 compatible :term:`neopixels <neopixel>`
  as you can reasonably fit on your tree; note these do not have to be the same
  model, RGB ordering, or length

* Whatever attachments you need to connect your neopixels to your :term:`Pico`
  or your carrier board; if you're lucky your strands will already have
  compatible connectors attached, if not you may need to solder and/or crimp
  some on yourself

* A box made of a non-flammable material large enough to house the power
  supply, breadboard, and all associated wiring

* Some cable glands large enough to accommodate at least the mains cable, and
  optionally the neopixel cables

* A couple of cable ties

In this tutorial I'll be using an `63-line breadboard`_ with two separate power
rails which is probably overkill, but I don't like being cramped when wiring
things! For the neopixels, I'll be using a `50-LED strand of RGB WS2812
neopixels`_, and a 100-LED strand of GRB WS2812 neopixels because that's what
was lying around.

.. _3B+: https://www.raspberrypi.com/products/raspberry-pi-3-model-b-plus/
.. _Pico W: https://www.raspberrypi.com/products/raspberry-pi-pico/
.. _Pico 2W: https://www.raspberrypi.com/products/raspberry-pi-pico-2/
.. _Pico Plus 2W: https://shop.pimoroni.com/products/pimoroni-pico-plus-2-w
.. _breadboard: https://en.wikipedia.org/wiki/Breadboard
.. _63-line breadboard: https://shop.pimoroni.com/products/solderless-breadboard-830-point
.. _Jumper leads: https://shop.pimoroni.com/products/jumper-jerky
.. _50-LED strand of RGB WS2812 neopixels: https://shop.pimoroni.com/products/5m-flexible-rgb-led-wire-50-rgb-leds-aka-neopixel-ws2812-sk6812

----

.. [#pi5] Note this set up has *not* been tested on a Raspberry Pi 5, on
   which the legacy camera stack does not work. The gstreamer camera stack
   *may* work on this model (in future I should add a libcamera based option).

.. [#v3] Note this has *not* been tested on a v3 camera module which is
   incompatible with the legacy camera stack. The gstreamer camera stack *may*
   work on this model (but again, I should add a libcamera based option).

.. [#webcam] Note that web-cams typically have *much* lower resolutions than
   Raspberry Pi camera modules, and higher resolutions are better for
   calibration.

.. [#othermcu] This project won't work out of the box on other microcontrollers
   as it's using the Pico's PIOs to drive the neopixels. That said it's not
   hard to adjust the Pico's scripts (they're just MicroPython) so if anyone
   wants to try making it more generic, feel free!

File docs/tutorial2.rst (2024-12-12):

===================
I've got the Power!
===================

The power supply requires some consideration. Neopixels typically have a
maximum output power of 0.24W per :term:`LED` (at 5V). All told I've got 150
LEDs, so that's a total potential output of 150 × 0.24W = 36W, plus whatever's
required for the Pico but frankly that'll be so minimal by comparison it's not
worth worrying about.

At 5V that's 36W ÷ 5V = 7.2A which is *way* beyond the maximum output of the
typical micro-USB power supply used with Picos; these often top out at 1A or
2A.

We need something quite a bit bigger, and preferably with a decent amount of
overhead [#overhead]_. I'll be using an `5V 100W supply`_ which gives me 64W of
head-room, but I'd guesstimate that anything 50W+ should be sufficient.

The power supply used in the tutorial. A large metal cuboid with
          several screw terminals at the rear (for mains input and 5V outputs)
          all surrounded by perforated aluminium for passive air cooling

.. warning::

    Please note that most of these supplies do not come with mains cables. This
    is why I included "being comfortable with wiring mains cables to a power
    supply" in the skills list at the top. You will need to be confident that
    you know which leads are live, neutral, and ground, when wiring this thing
    up.

The Heat Is On
==============

Another thing to consider is heat in your wiring. The mains leads should be
fine. At 240V, 100W is barely anything in amps: 100W ÷ 240V = 0.24A. However,
consider the 5V side of things.

We've already calculated we'll be pushing 7.2A through our wiring. Now the
individual LED strips themselves will only be taking what they need, so the
100-LED strip will take 4.8A (⅔ of 7.2A) and the 50-LED strip will take 2.4A (⅓
of 7.2A). However, the 5V wire running from the power supply will be carrying
the full 7.2A. With typical 24AWG solid-core wire that's okay.

But let me caution you on the hazards of scaling this up without thinking about
this! The first year I got this working, I used 150 LEDs, as we are in this
tutorial. The next year, I scaled it up to 250 LEDs thinking "there's more than
enough headroom in the power supply", but not considering the heating situation
on the 5V side of things. 250 × 0.24W = 60W. 60W ÷ 5V = 12A. Pushing 12A
through 24:term:`AWG` cable causes things to get *hot*:

A picture of the breadboard containing the Pico W and various linking
          various rows. Notably, one hole of the bottom positive rail is
          discoloured and clearly partially melted.

You can clearly see where I'd connected 5V from the power supply to the
breadboard … it's that melted hole on the bottom positive rail! I only noticed
this after taking everything apart after the holidays, and then realized (given
all this was housed rather carelessly in a spare cardboard box) just how close
I'd come to setting fire to the tree!

The moral of the story is: if you're planning to scale this beyond 150 LEDs,
please take the time to calculate how much ampage you're going to push through
your 5V wiring. If necessary, split the load across multiple supplies (most of
these supplies have multiple outputs), or get thicker gauge wire. And maybe
stick all this in a non-flammable box!

.. _5V 100W supply: https://www.amazon.co.uk/Baiyouli-Universal-Regulated-Switching-10W-300W/dp/B07D6R2ZBK

----

.. [#overhead] It's rarely a good idea to run power supplies near their limits.
   Even if they do manage it, you'll often experience voltage drops which can
   lead to brown-outs or crashes on your micro-controller. Such issues are
   notoriously hard to debug, so give yourself some reasonable overhead on the
   power supply.

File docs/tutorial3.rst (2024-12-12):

========
Pi Setup
========

We'll start with the Pi side of things as that's relatively easy. I'll be using
`Ubuntu for the Raspberry Pi`_ rather than the more common RaspiOS mostly
because it's what I'm more familiar with [#job]_. More specifically, I'll be
using the 32-bit armhf variant of 22.04 because the legacy camera stack doesn't
work on arm64 [#raspios]_ or on the later versions of Ubuntu.

#. Insert your :term:`SD card` into your computer, download `rpi-imager`_ (if
   you haven't got it already), and start it.

#. Select "CHOOSE DEVICE" and pick your model of Pi from the list (I'll be
   picking "Raspberry Pi 3" which includes the 3B+).

#. Select "CHOOSE OS", then "Other general-purpose OS", then "Ubuntu", then
   "Ubuntu Server 22.04.3 LTS (32-bit)".

#. Select "CHOOSE STORAGE", and pick your SD card from the list.

#. Select "NEXT", and follow the prompts to flash your SD card. Don't worry
   about customizing the first-time configuration because we're going to do
   some of that manually to have ``cloud-init`` handle all the installation.

Once the :term:`SD card` is flashed, remove it from your computer, then
re-insert it. You should see the boot partition (named "system-boot") appear.
Open this, and look for the file named :file:`network-config`. Open this in
your favoured text editor and replace the contents with the following, changing
the commented values as appropriate:

.. code-block:: yaml
    :emphasize-lines: 5,9-10

    network:
      version: 2
      wifis:
        wlan0:
          regulatory-domain: "GB"  # Replace with your country code
          dhcp4: true
          optional: false
          access-points:
            myhomewifi:            # Replace with your wifi SSID
              password: "S3kr1t"   # Replace with your wifi password

Next, open the :file:`user-data` file and replace the contents with the
following, changing the commented values as appropriate:

.. code-block:: yaml
    :emphasize-lines: 5

    hostname: blinkenxmas

    ssh_pwauth: false
    ssh_import_id:
    - gh:waveform80         # Replace with gh:your-github-username

    apt:
      sources:
        blinkenxmas:
          source: "ppa:waveform/blinkenxmas"

    package_update: true
    package_upgrade: true

    packages:
    - avahi-daemon
    - blinkenxmas-server

Finally, open the :file:`config.txt` file, comment out the camera and display
auto-detect lines, and append the highlighted lines to the end to enable the
legacy camera stack [#legacy]_:

.. code-block:: ini
    :emphasize-lines: 33-34,42-43

    [all]
    kernel=vmlinuz
    cmdline=cmdline.txt
    initramfs initrd.img followkernel

    [pi4]
    max_framebuffers=2
    arm_boost=1

    [all]
    # Enable the audio output, I2C and SPI interfaces on the GPIO header. As these
    # parameters related to the base device-tree they must appear *before* any
    # other dtoverlay= specification
    dtparam=audio=on
    dtparam=i2c_arm=on
    dtparam=spi=on

    # Comment out the following line if the edges of the desktop appear outside
    # the edges of your display
    disable_overscan=1

    # If you have issues with audio, you may try uncommenting the following line
    # which forces the HDMI output into HDMI mode instead of DVI (which doesn't
    # support audio output)
    #hdmi_drive=2

    # Enable the serial pins
    enable_uart=1

    # Autoload overlays for any recognized cameras or displays that are attached
    # to the CSI/DSI ports. Please note this is for libcamera support, *not* for
    # the legacy camera stack
    #camera_auto_detect=1
    #display_auto_detect=1

    [cm4]
    # Enable the USB2 outputs on the IO board (assuming your CM4 is plugged into
    # such a board)
    dtoverlay=dwc2,dr_mode=host

    [all]
    start_x=1
    gpu_mem=128

This should configure the Pi to connect to your WiFi network, import your
:term:`SSH` keys from your GitHub username [#sshkeys]_, and install everything
necessary on the first boot. Speaking of which...

First boot
==========

#. Eject the :term:`SD card` from your computer, and insert it in your Pi

#. Connect the camera module to your Pi

#. Plug in your Pi and let it run through the first boot (this will take a
   while because of all the things we've asked ``cloud-init`` to handle)

I would advise having a monitor attached for the first boot just to make sure
everything works successfully, but if you're *really* confident this isn't
strictly necessary and after a little while you should be able to just SSH to
``ubuntu@blinkenxmas.local`` (the ``.local`` domain is because we're using
`Avahi's mDNS`_ to find the Pi regardless of its IP address).

Finishing touches
=================

All the necessary software should have been installed by cloud-init, so all
that remains is for us to reconfigure things a little. Edit the
:file:`/etc/blinkenxmas.conf` file changing the highlighted lines below
(comments have been excluded for brevity):

.. code-block:: ini
    :emphasize-lines: 2,12-13,16,20-23,25-37

    [mqtt]
    host = blinkenxmas
    port = 1883
    topic = blinkenxmas

    [web]
    bind = 127.0.0.1
    port = 8000
    database = /var/cache/blinkenxmas/presets.db

    [wifi]
    ssid = your-ssid-here
    password = your-wifi-password-here

    [pico]
    status = 22
    error = reset

    [camera]
    type = picamera
    capture = 2592x1944
    preview = 640x480
    rotate = 0

    [leds:1]
    driver = WS2812
    count = 50
    fps = 60
    order = RGB
    pin = 15

    [leds:2]
    driver = WS2812
    count = 100
    fps = 60
    order = GRB
    pin = 16

.. note::

    The file is owned by root, so you will need to use :manpage:`sudo(1)` with
    your editor.

With the file updated, we need to add the ``blinkenxmas`` user to the ``video``
group so that it can access the Pi's camera, set the ``blinkenxmas`` site to be
nginx's default, and restart the ``blinkenxmas-server`` service:

.. code-block:: console

    $ sudo adduser blinkenxmas video
    $ cd /etc/nginx/sites-enabled
    $ sudo ln -sf ../sites-available/blinkenxmas default
    $ sudo systemctl restart blinkenxmas-server.service

.. _Ubuntu for the Raspberry Pi: https://ubuntu.com/raspberry-pi
.. _my job: https://waldorf.waveform.org.uk/pages/about.html
.. _rpi-imager: https://www.raspberrypi.com/software/
.. _Avahi's mDNS: https://en.wikipedia.org/wiki/Multicast_DNS

----

.. [#job] It's `my job`_ after all!

.. [#raspios] If you want to try getting this working on RaspiOS, please do (it
   would be useful to add to this, or another, tutorial) but be aware you'll
   almost certainly have to use the gstreamer configuration (unless I get
   around to writing that libcamera backend …)

.. [#legacy] These options enable the legacy camera stack on the Pi. If you're
   going to be using gstreamer instead, skip this step.

.. [#sshkeys] If you don't have this configured, you *can* comment out the
   ``ssh_import_id`` section and enable ``ssh_pwauth`` instead but I would
   strongly advise getting SSH keys configured on GitHub instead. It'll make
   things so much easier for you in future (and is much more secure)!

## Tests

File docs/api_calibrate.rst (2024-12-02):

=====================
blinkenxmas.calibrate
=====================

.. module:: blinkenxmas.calibrate

The :mod:`blinkenxmas.calibrate` module defines the classes associated with
calculating the 3D position of LEDs on the tree. The first phase consists of
:class:`AngleScanner`, which uses the camera to capture images of the tree. A
base "unlit" image is capture, then images with each LED lit in turn. The
scanner then uses some simple image manipulations (masking, gaussian blur, and
saturated subtractions) to determine the likely 2D position of each LED for the
particular angle of the tree.

In the second phase, :class:`PositionsCalculator` takes the 2D positions and
the angles they were captured at. It uses some simple trigonometry to calculate
the likely 3D position of each LED, trying to eliminate bad estimations using
derived "scores".

.. warning::

    At present, much of this module is undocumented as it's the result of
    several late nights, dredging up long bit-rotted trigonometric knowledge,
    querying StackExchange, and random experimentation. It's by far the most
    interesting module in the project, but equally I can only apologize to
    anyone trying to understand it!

Classes
=======

.. autoclass:: AngleScanner

.. autoclass:: PositionsCalculator

.. autoclass:: Calibration

Exceptions
==========

.. autoexception:: PointNotFound

Utility functions
=================

.. autofunction:: weighted_median

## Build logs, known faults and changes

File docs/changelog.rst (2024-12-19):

=========
Changelog
=========

Release 0.7.2 (2024-12-19)
==========================

* Fix crash in calibration due to invalid warning message

Release 0.7 (2024-12-17)
========================

* Fix width of calibration base capture in mask page
* Fix reload of mask page; now should re-capture base image
* Spruced up the logo!

Release 0.6 (2024-12-15)
========================

* Fixed creation page so it actually creates thing again...
* Fixed no-JS operation for everything except calibration
* Improved calibration with alignment line for the preview and better
  instructions
* More work on the tutorial

Release 0.5 (2024-12-12)
========================

* Fix missing manage page template
* More work on the tutorial

Release 0.4 (2024-12-07)
========================

* Fixed bug in bxflash so that it works even if the firmware is already running
  on the Pico W
* Re-wrote the preset removal page so it's much simpler
* More work on the tutorial

Release 0.3 (2024-12-05)
========================

* Fix a bug in the Pico configuration script (wrong status LED value)
* Fix several bugs in the HTTP server's JSON handling
* More work on the tutorial

Release 0.2 (2024-12-04)
========================

* Fix doc package builds
* More work on the tutorial

Release 0.1 (2024-12-03)
========================

* First experimental release to PPA

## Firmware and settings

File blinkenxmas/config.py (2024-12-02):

import os
import socket
from pathlib import Path
from contextlib import suppress
from fnmatch import fnmatchcase
from itertools import accumulate, chain
from argparse import ArgumentParser, SUPPRESS
from configparser import ConfigParser

# NOTE: The fallback comes first here as Python 3.7 incorporates
# importlib.resources but at a version incompatible with our requirements.
# Ultimately the try clause should be removed in favour of the except clause
# once compatibility moves beyond Python 3.9
try:
    import importlib_resources as resources
except ImportError:
    from importlib import resources

# NOTE: Remove except when compatibility moves beyond Python 3.8
try:
    from importlib.metadata import version
except ImportError:
    from importlib_metadata import version


# The locations to attempt to read the configuration from
XDG_CONFIG_HOME = Path(os.environ.get('XDG_CONFIG_HOME', '~/.config'))
CONFIG_LOCATIONS = (
    Path('/usr/local/etc/blinkenxmas.conf'),
    Path('/etc/blinkenxmas.conf'),
    Path(XDG_CONFIG_HOME / 'blinkenxmas.conf'),
)

# The set of keys within the configuration that represent paths and thus need
# to be resolved relative to the configuration file they were read from
CONFIG_PATHS = {
    # section,  key
    ('web',    'database'),
    ('camera', 'path'),
    ('camera', 'device'),
}


class ConfigArgumentParser(ArgumentParser):
    """
    A variant of :class:`~argparse.ArgumentParser` that links arguments to
    specified keys in a :class:`~configparser.ConfigParser` instance.
    """
    def __init__(self, *args, **kwargs):
        super().__init__(*args, **kwargs)
        self._config_map = {}

    def add_argument(self, *args, section=None, key=None, **kwargs):
        """
        Adds *section* and *key* parameters. These link the new argument to the
        specified configuration entry.

        The default for the argument can be specified directly as usual, or
        can be read from the configuration (see :meth:`set_defaults`). When
        arguments are parsed, the value assigned to this argument will be
        copied to the associated configuration entry.
        """
        return self._add_config_action(
            *args, method=super().add_argument, section=section, key=key,
            **kwargs)

    def add_argument_group(self, title=None, description=None, section=None):
        """
        Adds a new argument group object and returns it.

        The new argument group will likewise accept *section* and *key*
        parameters on its :meth:`add_argument` method. The *section* parameter
        will default to the value of the *section* parameter passed to this
        method (but may be explicitly overridden).
        """
        group = super().add_argument_group(title=title, description=description)
        def add_argument(*args, section=section, key=None,
                         _add_arg=group.add_argument, **kwargs):
            return self._add_config_action(
                *args, method=_add_arg, section=section, key=key, **kwargs)
        group.add_argument = add_argument
        return group

    def _add_config_action(self, *args, method, section, key, **kwargs):
        assert callable(method), 'method must be a callable'
        if (section is None) != (key is None):
            raise ValueError('section and key must be specified together')
        try:
            if kwargs['action'] in ('store_true', 'store_false'):
                type = boolean
        except KeyError:
            type = kwargs.get('type', str)
        action = method(*args, **kwargs)
        if key is not None:
            with suppress(KeyError):
                if self._config_map[action.dest] != (section, key, type):
                    raise ValueError(
                        'section and key must match for all equivalent dest '
                        'values')
            self._config_map[action.dest] = (section, key, type)
        return action

    def set_defaults_from(self, config):
        """
        Sets defaults for all arguments from their associated configuration
        entries in *config*.
        """
        kwargs = {
            dest:
                config.getboolean(section, key)
                if type is boolean else
                config[section][key]
            for dest, (section, key, type) in self._config_map.items()
            if section in config
            and key in config[section]
        }
        return super().set_defaults(**kwargs)

    def update_config(self, config, namespace):
        """
        Copy values from *namespace* (presumably the result of calling
        something like :meth:`~argparse.ArgumentParser.parse_args`) to
        *config*. Note that namespace values will be converted to :class:`str`
        implicitly.
        """
        for dest, (section, key, type) in self._config_map.items():
            config[section][key] = str(getattr(namespace, dest))
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

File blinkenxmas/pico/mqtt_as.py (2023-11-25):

# mqtt_as.py Asynchronous version of umqtt.robust
# (C) Copyright Peter Hinch 2017-2022.
# Released under the MIT licence.

# Pyboard D support added also RP2/default
# Various improvements contributed by Kevin Köck.

import gc
import socket
import struct

gc.collect()
from binascii import hexlify
import asyncio

gc.collect()
from time import ticks_ms, ticks_diff
from errno import EINPROGRESS, ETIMEDOUT

gc.collect()
from micropython import const
from machine import unique_id
import network

gc.collect()
from sys import platform

VERSION = (0, 7, 0)

# Default short delay for good SynCom throughput (avoid sleep(0) with SynCom).
_DEFAULT_MS = const(20)
_SOCKET_POLL_DELAY = const(5)  # 100ms added greatly to publish latency

# Legitimate errors while waiting on a socket. See uasyncio __init__.py open_connection().
ESP32 = platform == "esp32"
RP2 = platform == "rp2"
if ESP32:
    # https://forum.micropython.org/viewtopic.php?f=16&t=3608&p=20942#p20942
    BUSY_ERRORS = [EINPROGRESS, ETIMEDOUT, 118, 119]  # Add in weird ESP32 errors
elif RP2:
    BUSY_ERRORS = [EINPROGRESS, ETIMEDOUT, -110]
else:
    BUSY_ERRORS = [EINPROGRESS, ETIMEDOUT]

ESP8266 = platform == "esp8266"
PYBOARD = platform == "pyboard"

# Default "do little" coro for optional user replacement
async def eliza(*_):  # e.g. via set_wifi_handler(coro): see test program
    await asyncio.sleep_ms(_DEFAULT_MS)


class MsgQueue:
    def __init__(self, size):
        self._q = [0 for _ in range(max(size, 4))]
        self._size = size
        self._wi = 0
        self._ri = 0
        self._evt = asyncio.Event()
        self.discards = 0

    def put(self, *v):
        self._q[self._wi] = v
        self._evt.set()
        self._wi = (self._wi + 1) % self._size
        if self._wi == self._ri:  # Would indicate empty
            self._ri = (self._ri + 1) % self._size  # Discard a message
            self.discards += 1

    def __aiter__(self):
        return self

    async def __anext__(self):
        if self._ri == self._wi:  # Empty
            self._evt.clear()
            await self._evt.wait()
        r = self._q[self._ri]
        self._ri = (self._ri + 1) % self._size
        return r


config = {
    "client_id": hexlify(unique_id()),
    "server": None,
    "port": 0,
    "user": "",
    "password": "",
    "keepalive": 60,
    "ping_interval": 0,
    "ssl": False,
    "ssl_params": {},
    "response_time": 10,
    "clean_init": True,
    "clean": True,
    "max_repubs": 4,
    "will": None,
    "subs_cb": lambda *_: None,
    "wifi_coro": eliza,
    "connect_coro": eliza,
    "ssid": None,
    "wifi_pw": None,
    "queue_len": 0,
}


class MQTTException(Exception):
    pass


def pid_gen():
    pid = 0
    while True:
        pid = pid + 1 if pid < 65535 else 1
        yield pid


def qos_check(qos):
    if not (qos == 0 or qos == 1):
        raise ValueError("Only qos 0 and 1 are supported.")


# MQTT_base class. Handles MQTT protocol on the basis of a good connection.
# Exceptions from connectivity failures are handled by MQTTClient subclass.
class MQTT_base:
    REPUB_COUNT = 0  # TEST
    DEBUG = False

    def __init__(self, config):
        self._events = config["queue_len"] > 0
        # MQTT config
        self._client_id = config["client_id"]
        self._user = config["user"]
        self._pswd = config["password"]
        self._keepalive = config["keepalive"]
        if self._keepalive >= 65536:
            raise ValueError("invalid keepalive time")
        self._response_time = config["response_time"] * 1000  # Repub if no PUBACK received (ms).
        self._max_repubs = config["max_repubs"]
        self._clean_init = config["clean_init"]  # clean_session state on first connection
        self._clean = config["clean"]  # clean_session state on reconnect
        will = config["will"]
        if will is None:
            self._lw_topic = False
        else:
            self._set_last_will(*will)
        # WiFi config
        self._ssid = config["ssid"]  # Required for ESP32 / Pyboard D. Optional ESP8266
        self._wifi_pw = config["wifi_pw"]
        self._ssl = config["ssl"]
        self._ssl_params = config["ssl_params"]
        # Callbacks and coros
        if self._events:
            self.up = asyncio.Event()
            self.down = asyncio.Event()
            self.queue = MsgQueue(config["queue_len"])
        else:  # Callbacks
            self._cb = config["subs_cb"]
            self._wifi_handler = config["wifi_coro"]
            self._connect_handler = config["connect_coro"]
        # Network
        self.port = config["port"]
        if self.port == 0:
            self.port = 8883 if self._ssl else 1883
        self.server = config["server"]
        if self.server is None:
            raise ValueError("no server specified.")
        self._sock = None
        self._sta_if = network.WLAN(network.STA_IF)
        self._sta_if.active(True)

        self.newpid = pid_gen()
        self.rcv_pids = set()  # PUBACK and SUBACK pids awaiting ACK response
        self.last_rx = ticks_ms()  # Time of last communication from broker
        self.lock = asyncio.Lock()

    def _set_last_will(self, topic, msg, retain=False, qos=0):
        qos_check(qos)
        if not topic:
            raise ValueError("Empty topic.")
        self._lw_topic = topic
        self._lw_msg = msg
        self._lw_qos = qos
        self._lw_retain = retain

    def dprint(self, msg, *args):
        if self.DEBUG:
            print(msg % args)

    def _timeout(self, t):
        return ticks_diff(ticks_ms(), t) > self._response_time

    async def _as_read(self, n, sock=None):  # OSError caught by superclass
        if sock is None:
            sock = self._sock
        # Declare a byte array of size n. That space is needed anyway, better
        # to just 'allocate' it in one go instead of appending to an
        # existing object, this prevents reallocation and fragmentation.
        data = bytearray(n)
        buffer = memoryview(data)
        size = 0
        t = ticks_ms()
        while size < n:
            if self._timeout(t) or not self.isconnected():
                raise OSError(-1, "Timeout on socket read")
            try:
                msg_size = sock.readinto(buffer[size:], n - size)
            except OSError as e:  # ESP32 issues weird 119 errors here
                msg_size = None
                if e.args[0] not in BUSY_ERRORS:
                    raise
            if msg_size == 0:  # Connection closed by host
                raise OSError(-1, "Connection closed by host")
            if msg_size is not None:  # data received
                size += msg_size
                t = ticks_ms()
                self.last_rx = ticks_ms()
            await asyncio.sleep_ms(_SOCKET_POLL_DELAY)
        return data

    async def _as_write(self, bytes_wr, length=0, sock=None):
        if sock is None:
            sock = self._sock
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

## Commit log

2022-11-14 Fix missing imports and msg decoding
    [blinkenxmas.py]
2022-11-15 Fix subscription and only init LEDs at the top level
    [blinkenxmas.py]
2022-11-15 Move pico stuff under its own dir
2022-11-15 Use chameleon for templating; switch to importlib.resources
2022-11-16 Re-work HTTP handling
    Using something framework-like routes sort of thing and split all the
    dynamic stuff into simple functions in their own module
2022-11-17 And fix all the breakage...
    [http.py, httpd.py, routes.py]
2022-11-20 Switch to byte-string for animation txns
    Also have all animation functions return the full animation (easier to
    preview on the command-line with colorzero)
2022-11-21 Add a preview function and some more animations
    And remove an optimization that turns out to cause issues with
    animations that rely on all-black frames at the start
    [animations.py, routes.py]
2022-11-22 Change animation representation
    The representation at the web-page is now a list of lists of HTML color
    strings. The representation at the pico is a list of lists of (index,
    rgb565) changes which is much more memory efficient (a full 10 second
    animation now takes barely 10KB)
2022-11-25 Improve error handling
    Use numbered blinks to indicate current state; add an exception handler
    to shut down existing tasks on crash (and indicate error state with
    5-blinks -- this should eventually be replaced by reset / soft-reset or
    something like that). Also output size of message on reception
    [blinkenxmas.py]
2022-11-26 Add configurable error handling
    [blinkenxmas.py]
2022-11-28 Permit multiple LED strips to be configured
    Each strip will be driven by a separate PIO state machine, can be a mix
    of WS2812 and APA102s of arbitrary length and optionally reversed. Also
    split the classes into separate modules to keep the code reasonably
    readable.
    [animation.py, blinkenxmas.py, leds.py]
2022-11-29 Make the status LED configurable
2022-11-30 Lots of forms work
    Create page now works fully, home-page displays presets nicely, added a
    (non-functional) manage button, and fixed up mobile styles.
    [forms.js, messages.js]
2022-12-01 Show Create button when no presets are defined
2022-12-13 Start work on calibration
    Add a positions table to the database; move the httpd options back to
    global config; add a rough calibration page template and an abstract
    Source class plus some sketches of sources for picamera and
    file-sources.
2022-12-17 First stab at a configurable calibration camera
    Currenty untested, supports three camera types: files, gstreamer or
    picamera.
2022-12-17 Add default for gstreamer device
2022-12-17 Add scripts to calibration form
2022-12-17 Add calibration status to form
2022-12-17 Split forms.js up into individual units
    Each form doesn't share much (if any) code so it makes sense to split
    'em all up
    [calibrate.js, create.js, messages.js]
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2022-12-18 Include all leds: sections
    This ensures all keys are included when validating the configuration
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2022-12-18 Ensure config errors are raised in the try: block
    [cli.py, web.py]
2022-12-18 Shift main logic into a routine
    This simplifies debugging as breaking into the routine doesn't prevent
    the blinkenxmas import, leaving the mqtt client and leds objects
    accessible for debugging
    [blinkenxmas.py]
2022-12-18 Unify struct definitions
    Move the pico code into a module of blinkenxmas itself and permit
    blinkenxmas to import the struct definitions from it (with some
    monkey-patching horror).
2022-12-19 Fix _anim_path ref
    And use memoryview for more efficient slicing of the written buffer
    [animation.py]
2022-12-19 Fix prototype of animate
    [blinkenxmas.py]
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2022-12-20 Fix path resolution and ~ expansion
    [config.py]
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2022-12-22 Finish camera implementation
    All more or less works at this point, in terms of preview and capture at
    least with GStreamer and file-based input.
2022-12-26 Calibration of angle 0 working
    with live progress display and preview image of positions
2023-05-29 Return correct code for PUT
    [routes.py]
2023-11-25 Fix cancellation of calibration
    [routes.py]
2023-11-25 Define strips of LEDs
    It's not enough to have an overall count of LEDs as strips can have
    different RGB orderings. This commit also substantially re-writes some
    of the calibration logic. Getting closer to something working...
2023-11-25 Fix bxcli help, list, and show
    [cli.py]
2023-11-25 No need to call soft_reset
    When we exit and error is set to reset it's going to reboot anyway. Need
    to find some way to tell it to exit "normally" for flashing...
    [flash.py]
2023-11-25 Rename micropython modules
    MP's started removing "u" prefixes from various standard modules; to
    avoid duplication in sys.modules, we should do likewise (it doesn't
    duplicate the module, just the entry, but still ... it's wasted RAM!)
    [blinkenxmas.py, leds.py, mqtt_as.py]
2023-11-25 Only calibrate white, and calculate the count correctly
    There's no point calibrating different colours; white will enable all
    LEDs and stands the best chance at producing a diff to the base frame.
    Haven't stripped the colour out of the dummy calibration yet...
    [calibrate.py]
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2023-11-26 Update blinkenxmas with hamstercam's http logic
    It's rather more complete and handles a whole bunch of caching scenarios
    along with partial range requests. However, it doesn't handle JSON quite
    as well so we need to patch that given how much we use it here.
    [cameras.py, config.py, create.js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]
2023-11-29 More calibration work
    We now reject diff'd positions with low scores or large areas, and the
    calibration returns to capture the next angle after it finishes
2023-11-30 Rename the Calibrate button to Scan
    That's what it's doing after all...
2023-12-01 Add the position calculator
    At this point we've got a basic 3D calibration mechanism, though now
    based on polar coordinates. The angle scanner now turns off the LEDs at
    the end of a scan (and generates the "scene" more efficiently). The
    positions calculator accepts multiple angle scanners and interpolates
    their guessed positions into a 3D model where each LED has a height from
    the base, and angle around the trunk, and a radius from the trunk.
    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
2023-12-01 Update the store with the new calibration format
    This replaces the cartesian positions with the polar positions now
    generated by the calibration logic. The upgrade does simply ditch the
    old positions without attempting to convert them, which is ... not
    great. But it's a once a year thing so nevermind!
    [store.py]
2023-12-02 Turn LEDs off *before* capturing base image
    Doh...
2023-12-02 Use class-specific loggers
    Need to add some --verbose switches and stuff...
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2023-12-02 Actually reset the Pico
    Soft-reset isn't enough for some errors
    [blinkenxmas.py]
2023-12-02 Fix a status message
    [calibrate.py]
2023-12-02 Add compression to the file transfer
    This is a pretty substantial change and risks running out of space on
    the Pico's internal storage (as it requires we store, unpack, remove
    archive instead of streaming the unpack because chunks can arrive out of
    order). Consider reverting if we run into issues.
    [animation.py, blinkenxmas.py, mqtt.py]
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2023-12-02 Add positions to animation parameters
    Actually, re-factor the parameters so that all parameters are explicitly
    declared and registered but some (like fps, LED count, LED positions)
    are handled by particular classes that pass input from the system rather
    than the user. This makes the route handler *much* simpler.
2023-12-03 Fix saturation and lightness in Pride
    [animations.py]
2023-12-07 Fix preview
    Very handy for debugging stuff!
    [animations.py]
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2023-12-08 Shorten twinkle
    Has a nasty tendency to overflow the Pico's storage when large number of
    LEDs are involved. Also tweak the language in the description a bit.
    [animations.py]
2023-12-18 Flip the sequence of bottom & top in Gradient
    [animations.py]
2023-12-18 Drop the keepalive to the default
    We seem to lose connection to the MQTT broker periodically on the Pi. I
    wonder if the long keepalive is the issue?
    [mqtt.py]
2023-12-18 Fix Plane Sweep
    Never get it right first time :)
    [animations.py]
2023-12-19 Make a start on the docs
    [tutorial.fzz]
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2023-12-21 Get the right type on the Manage button after Cancel...
2023-12-21 Handle errors in generateAnim properly
    [create.js]
2023-12-22 Fix parse_formdata
    The parser needs to respect Content-Length to deal with HTTP/1.1
    persistent connections. Also split out the buffer handling into its own
    class (much cleaner than all that nonlocal nonsense). Unfortunately, it
    turns out SpooledTemporaryFile is rather deficient prior to 3.11 so I
    needed to add a compat class for that...
    [compat.py, http.py]
2023-12-22 Fix checkbox handling in the creation form
    [create.js, routes.py]
2023-12-23 Fix bool value for checkbox controls
    [httpd.py]
2023-12-23 Label Create/Update according to preset name
    Change the Create button to Update to give a subtle warning to the user
    that they're going to overwrite a preset. A pop-up *might* be warranted
    here, but personally I think this is enough...
2023-12-23 Refine the config page a bit
    I don't like disappearing buttons. Better to have "disabled" stuff.
2023-12-24 Add a skills list and start work on the Pico section
2023-12-24 Fix bug in gradient by position
    linspace has a default for steps ... because of course it does
    [animations.py]
2024-11-30 Make messages a param and swap some orderings
    This just makes things a bit more comparable to hamstercam (another
    project which shares quite a bit of code with this one, but which I
    can't be bothered to break into its own library yet)
    [httpd.py, mqtt.py, web.py]
2024-11-30 A bit more work on the tutorial...
    ... pointing out the hazards of high-ampage draw over teeny tiny wires
2024-12-01 Start adapting tests to blinkenxmas
    Only 12 failures now...
    [test_config.py, test_http.py, test_httpd.py]
2024-12-01 Fix syntax for py3.7
    [web.py]
2024-12-02 Lots of work on the docs
    The API docs are about 80% complete. Should get all of that (with the
    possible exception of calibrate.py) finished this holiday. The
    application docs and tutorial really need finishing, but packaging work
    should probably come first...
2024-12-04 Fix link and legacy camera stack config
2024-12-06 Add fritzing files
    And export breadboard and schematic for tutorial
    [breadboard.fzz, stripboard.fzz]
2024-12-06 Use the correct config value for status LED
    [blinkenxmas.py]
2024-12-07 Raise KeyError correctly on missing deletion
    [store.py]
2024-12-07 Retrieving the query cannot fail with ValueError
    That's left-over from when this handler called .json()
    [routes.py]
2024-12-07 Ensure json() fails if called a second time
    And document that it's a one-shot handler
    [httpd.py]
2024-12-14 Add missing attribute docs
    [httpd.py]
2024-12-14 Correct docs for Param.choices
    It's a dict, not a set
    [httpd.py]
2024-12-15 Simplify the calibrate button
    You can perfectly well see if it's already calibrated, and the
    calibration page itself will tell you right at the top
2024-12-15 Finish no-JS implementation for preset creation
    Also overhauled the JS implementation to be a bit simpler. The "Custom"
    animation with a data box is now gone (never used it anyway), and the
    caching of the animation data is done in a dataset on the form itself.
    The "animations" and "presets" globals are now obtained from the server
    on-demand (to avoid serving a load of JSON to browsers that aren't going
    to use it anyway). Finally, fixed up non-click submission in the
    creation form.
    [create.js, globals.js, httpd.py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]
2024-12-15 Improve calibration
    Draw an alignment line down the centre of the preview for users to align
    the tree to. Improve some of the instructions.
2024-12-15 Fix the create form
    Don't delete the submit button...
    [create.js]
2024-12-15 Fix test-suite
    Broken by addition of Etag and change of caching logic
    [test_http.py, test_httpd.py]
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2024-12-15 Check animations are correctly decorated
    Crash out at start if animation's decorator doesn't match the required
    parameters of the function
    [httpd.py]
2024-12-17 Add source and docs config options
    And help buttons to link to the docs
2024-12-17 Fix re-load of calibration capture
    And width of captured image for masking
    [routes.py]
2024-12-18 Fix warning messages
    Invalid substitution in one and overly precise values everywhere else
    [calibrate.py]
